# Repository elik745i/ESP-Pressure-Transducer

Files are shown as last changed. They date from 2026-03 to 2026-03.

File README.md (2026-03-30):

# ESP Pressure Transducer

PlatformIO project for a Wemos D1 mini (ESP8266) pressure monitor with:

- 0.96 inch I2C OLED status display
- TTP223 touch sensor support for quick OLED unit switching
- web configuration page with in-firmware fallback if LittleFS content is missing
- Wi-Fi station mode plus fallback configuration access point
- captive portal behavior for easier AP setup on phones and laptops
- MQTT publishing for Home Assistant
- buzzer alarm window with configurable Min and Max limits
- buzzer volume control in the web UI and over MQTT
- touch sensor enable / disable control in the web UI and over MQTT
- Home Assistant MQTT discovery controls for Min / Max alarm settings in bar
- Home Assistant device metadata with a direct LAN configuration page link

## Hardware

Board and connections used by this project:

- Wemos D1 mini / ESP8266
- OLED SCL -> D1 / GPIO5
- OLED SDA -> D2 / GPIO4
- Buzzer -> D5 / GPIO14
- TTP223 touch output -> D6 / GPIO12
- Pressure sensor output -> 10K series resistor -> A0
- A0 -> 33K resistor -> GND

Configured sensor default:

- Full scale pressure: `1200 kPa` (`1.2 MPa`, `12 bar`)
- Default analog interpretation: `0.5 V` to `4.5 V` sensor output maps to `0` to `1200 kPa`

## Circuit Diagram

The wiring used for this project is shown below:

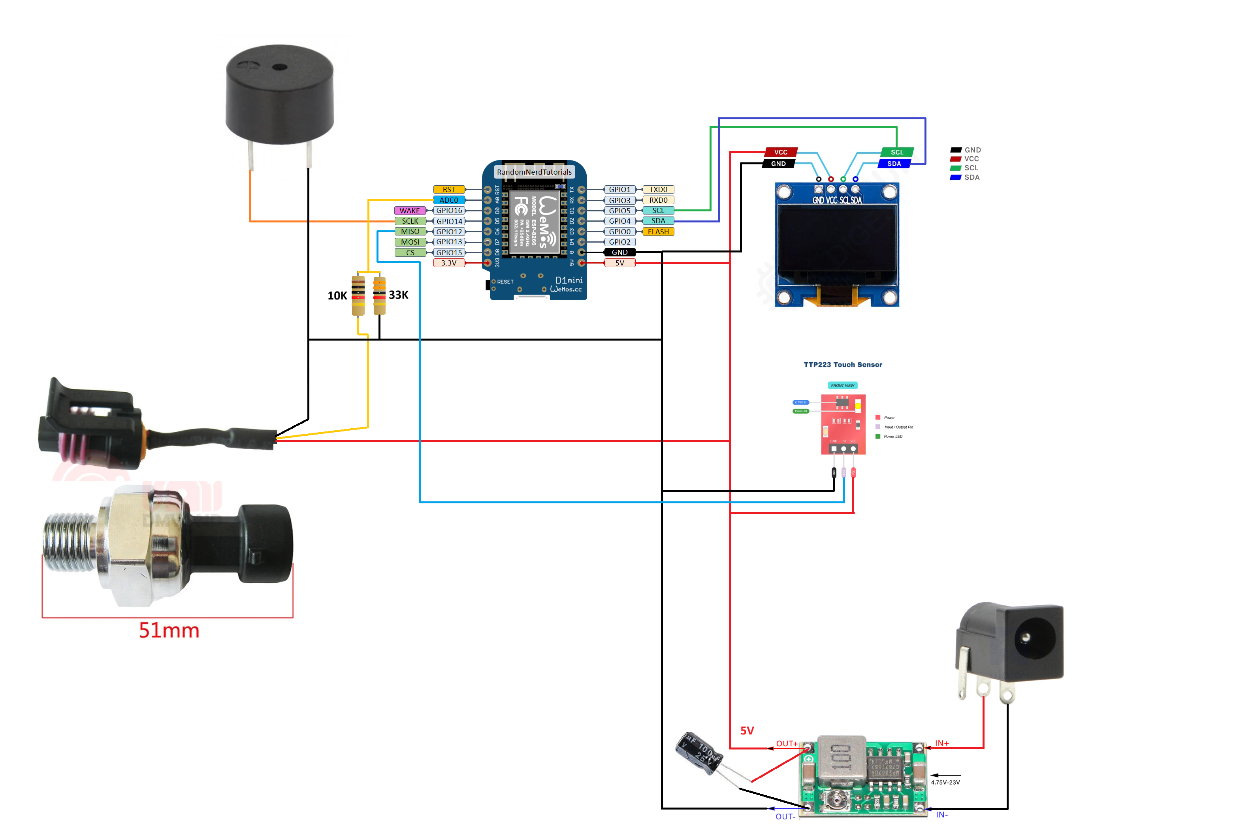
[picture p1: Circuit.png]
Circuit diagram


## Important Analog Note

This firmware assumes the **Wemos D1 mini A0 pin range is 0 to 3.2 V**, then reconstructs the original sensor voltage from your external `10K / 33K` divider.

That divider ratio is:

$$
V_{A0} = V_{sensor} \times \frac{33}{10 + 33} \approx 0.767 \times V_{sensor}
$$

If your sensor is powered at `5 V` and outputs up to `4.5 V`, the divided voltage is about:

$$
4.5 \times 0.767 \approx 3.45 V
$$

That is slightly above the usual safe `3.2 V` limit of a D1 mini A0 pin. If your real hardware reaches that level, reduce the divider ratio before long-term use.

## Project Layout

- [platformio.ini](platformio.ini)
- [src/main.cpp](src/main.cpp)
- [data/index.html](data/index.html)
- [.github/workflows/platformio.yml](.github/workflows/platformio.yml)

## VS Code Setup

1. Open this folder in VS Code.
2. Install the recommended extension: `PlatformIO IDE`.
3. Connect the Wemos D1 mini by USB.
4. In PlatformIO:
   1. Run `Upload` to flash the firmware.
   2. Optionally run `Upload Filesystem Image` to store [data/index.html](data/index.html) in LittleFS too.
   3. Open `Monitor` at `115200` baud if needed.

You can also use the PlatformIO toolbar buttons in the VS Code status bar.

If the PlatformIO status bar buttons are not visible, use VS Code task buttons instead:

1. Open `Terminal -> Run Task`.
2. Use one of these project tasks:
   1. `PlatformIO: Build`
   2. `PlatformIO: Upload`
   3. `PlatformIO: Upload Filesystem`
   4. `PlatformIO: Monitor`
   5. `PlatformIO: Clean`

These tasks are defined in [.vscode/tasks.json](.vscode/tasks.json) so the project remains easy to build and upload from the VS Code interface.

## Flashing Troubleshooting

If flashing fails or the CH340/CH341 serial adapter is not detected correctly on Windows, try installing the older CH341 driver included in this repository:

- [CH341SER/CH341SER.EXE](CH341SER/CH341SER.EXE)

The driver files are stored in the [CH341SER](CH341SER) folder in this git repository.

## First Boot

On first boot the device creates an access point:

- SSID: `PressureConfig-<chipid>`
- Password: `12345678`

Open:

- `http://192.168.4.1`

Many phones and laptops should also open the configuration page automatically through captive portal detection while connected to the device AP.

Set:

- Wi-Fi SSID and password
- MQTT broker host, port, username, password
- MQTT base topic
- Home Assistant discovery prefix
- sensor voltage calibration, full-scale pressure, and buzzer alarm min/max window

After saving, the device restarts automatically.

## OLED Touch Control

If a TTP223 touch sensor is connected to `D6 / GPIO12`, a short touch will:

- play a short confirmation beep on the buzzer
- switch the OLED pressure unit between `bar` and `psi`

This gives a quick way to change units directly on the device without opening the web UI.

The touch sensor can also be disabled entirely from the web UI or over MQTT.

## Firmware Updates

The Firmware tab supports two update methods:

- GitHub release discovery for available versions
- local `firmware.bin` upload through the web page

For ESP8266 reliability, the recommended OTA setup is:

- use GitHub for version discovery and release history
- host the actual `firmware.bin` on a simple direct static URL
- set `OTA Base URL` in the Firmware tab to:
  `https://your-host/esp-pressure-transducer`

Then the device downloads firmware from:

- `https://your-host/esp-pressure-transducer/<version>/firmware.bin`

If `OTA Base URL` is left empty, the firmware falls back to the GitHub release asset URL.

The local upload button is for:

- `firmware.bin`

Do not use `littlefs.bin` with the local upload button. `littlefs.bin` is only for manual flash-tool installs when you intentionally want to refresh the filesystem image.

## MQTT Topics

Default base topic:

- `home/pressure-<chipid>`

Published topics:

- `<baseTopic>/state`
- `<baseTopic>/availability`

The state payload includes:

- `pressure_kpa`
- `pressure_bar`
- `sensor_voltage`
- `a0_voltage`
- `raw_adc`
- `wifi_rssi`
- `ip`
- `alarm`
- `uptime_seconds`

If Home Assistant discovery is enabled, the firmware also publishes discovery topics under:

- `homeassistant/sensor/.../config`
- `homeassistant/number/.../config`

Home Assistant discovery includes:

- pressure sensor exposed in `bar`
- `Min` and `Max` number controls for the buzzer alarm window
- `Buzzer Volume` number control in percent
- `Touch Sensor` switch to enable or disable touch input
- a device `configuration_url` that points to the device's LAN page when Wi-Fi is connected

## GitHub Setup

This project is prepared for git and GitHub upload.

Suggested commands:

```powershell
git init
git checkout -b main
git add .
git commit -m "Initial ESP pressure transducer project"
git remote add origin https://github.com/elik745i/ESP-Pressure-Transducer.git
git push -u origin main
```

The repository already includes a GitHub Actions workflow that builds the PlatformIO project on pushes and pull requests.

## Notes

- Wi-Fi, MQTT, and device identity settings are stored in persistent EEPROM-backed storage so they survive filesystem refreshes.
- AP, calibration, OLED, and other non-critical settings are stored in LittleFS at `/config.json`.
- The web UI is compiled into firmware and can also be stored separately in LittleFS as [data/index.html](data/index.html).
- The Firmware tab can remember the last open tab in the browser and reopen it after refresh.
- The OLED shows live pressure, Wi-Fi state, and MQTT state.
- A TTP223 touch sensor on `D6 / GPIO12` can toggle the OLED between `bar` and `psi` with a short beep.
- Buzzer volume is adjustable from `0` to `100%` and is retained in device configuration.
- Touch sensor enable / disable is retained in device configuration and available over MQTT.
- The alarm logic now uses hysteresis and reports low-side and high-side alarm activity separately in the status payload.
- The built-in LED uses different blink patterns for boot, AP-only mode, Wi-Fi connection attempts, Wi-Fi connected, MQTT connected, and restart pending.

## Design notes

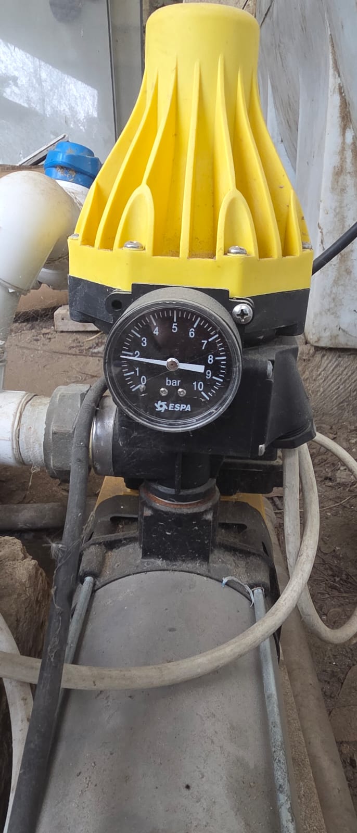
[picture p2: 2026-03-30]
Docs/espa1.jpeg

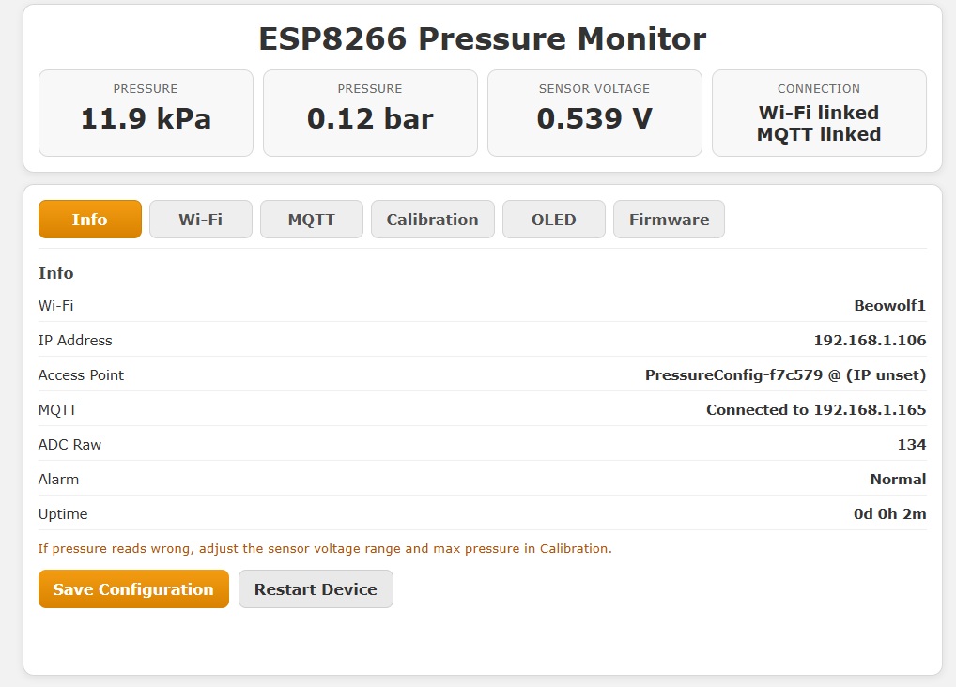
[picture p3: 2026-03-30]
Docs/web.jpg

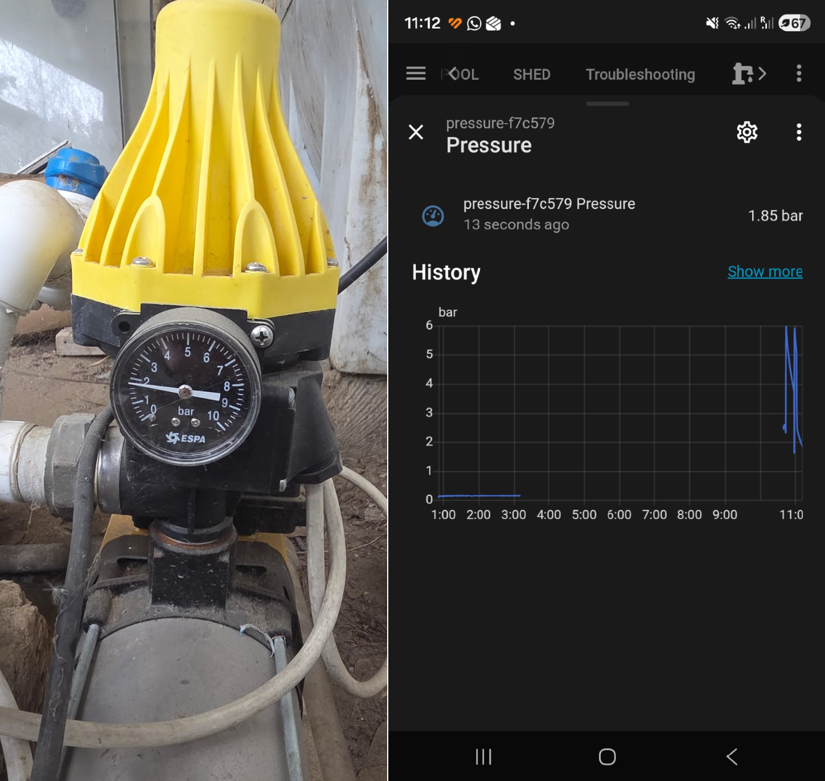
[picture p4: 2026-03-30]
Docs/correction.png

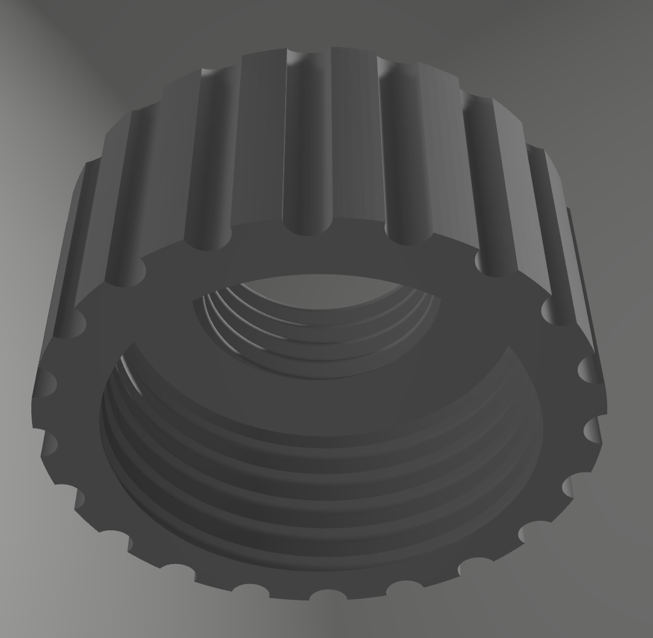
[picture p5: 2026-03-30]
Docs/xover.png

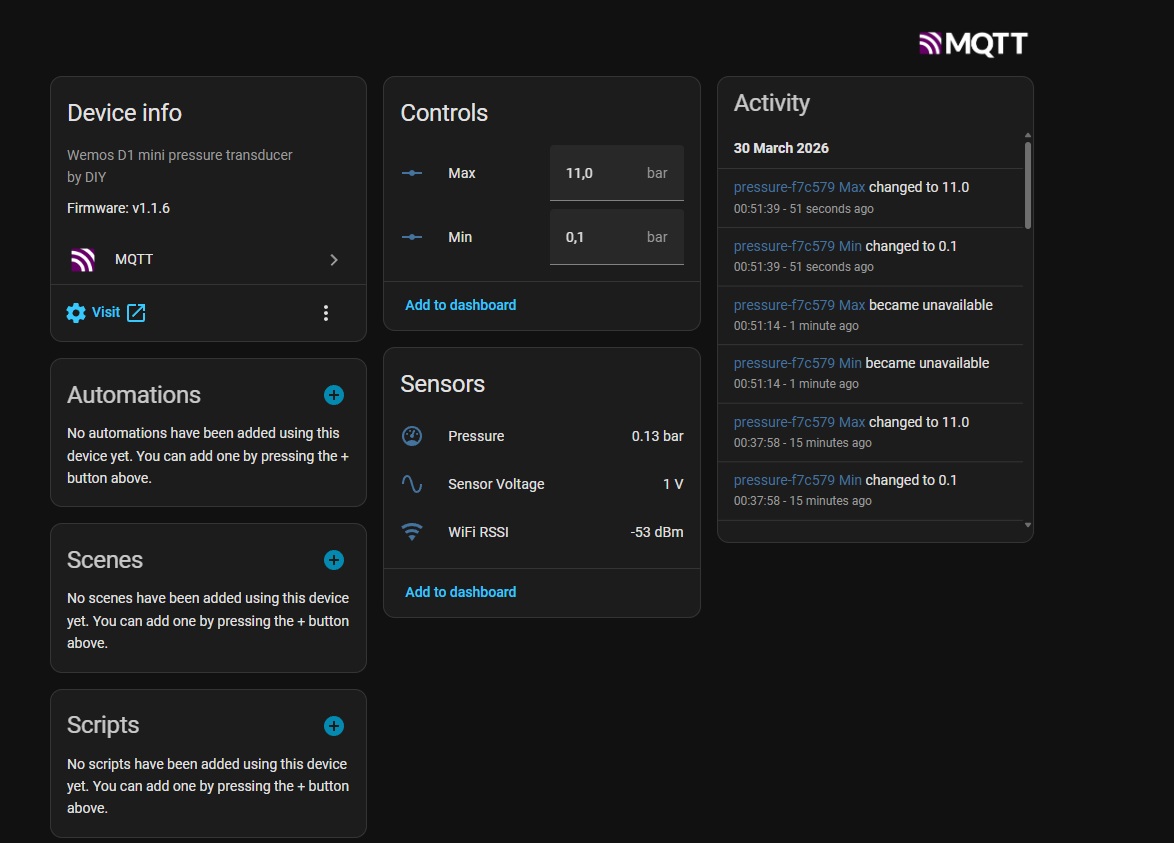
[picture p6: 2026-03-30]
Docs/HA.jpg

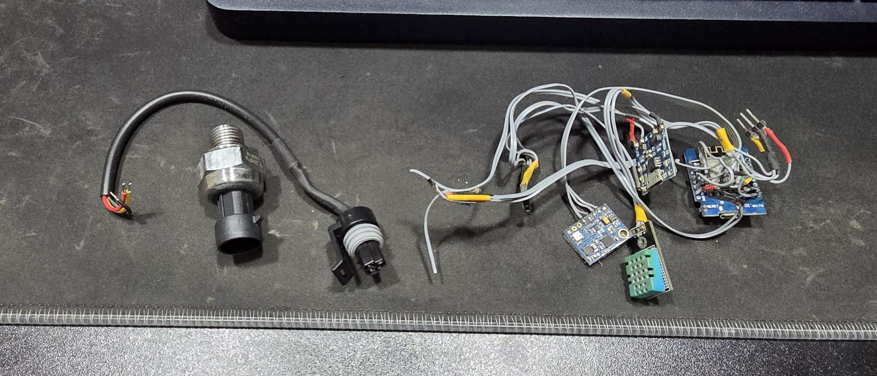
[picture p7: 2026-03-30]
Docs/next_one.jpeg

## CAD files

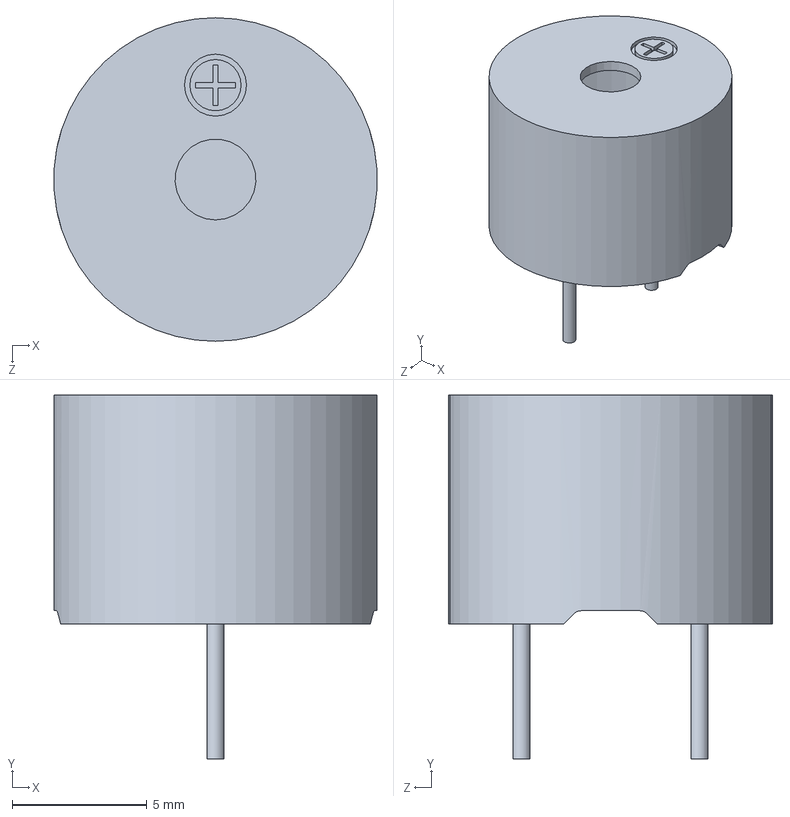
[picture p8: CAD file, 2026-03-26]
3D/3d_Models/buzzer-hc-12085-1.snapshot.1/Buzzer.SLDPRT
12.0 x 13.5 x 12.0 mm

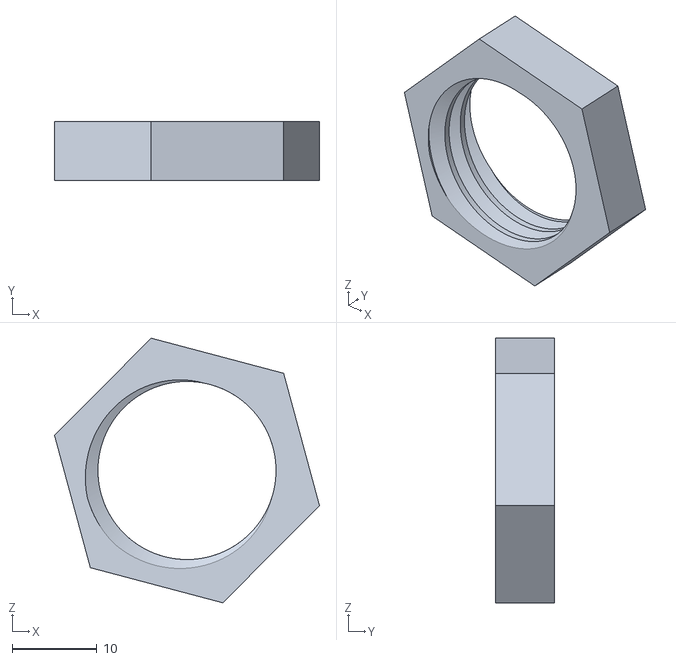
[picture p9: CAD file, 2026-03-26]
3D/3d_Models/cable-gland-18.snapshot.6/sph17mmB.stl
31.3 x 7.00 x 31.2

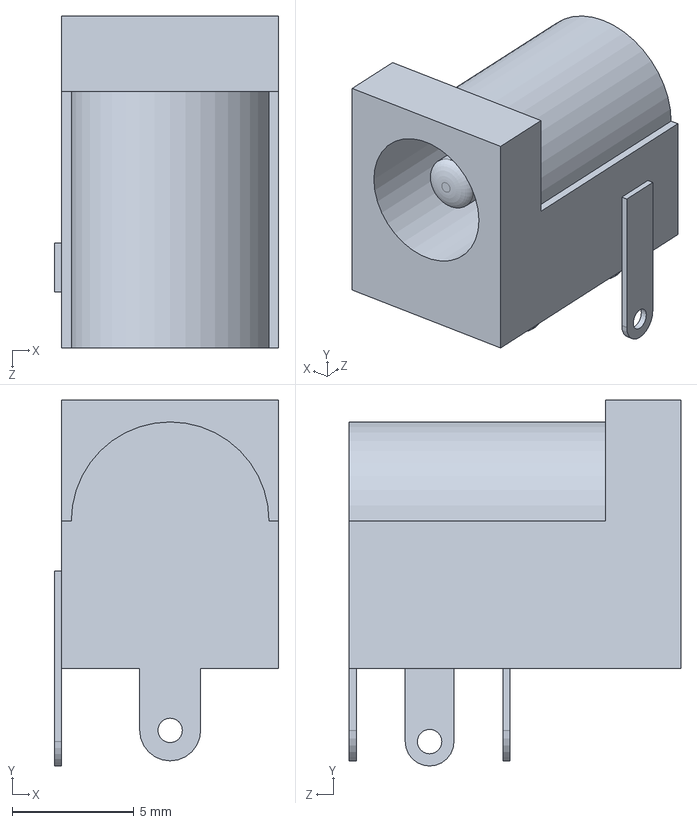
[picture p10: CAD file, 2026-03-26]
3D/3d_Models/jack_dc_2-5-1.snapshot.1/Conector_jack_2.5.SLDPRT
9.20 x 15.0 x 13.6 mm

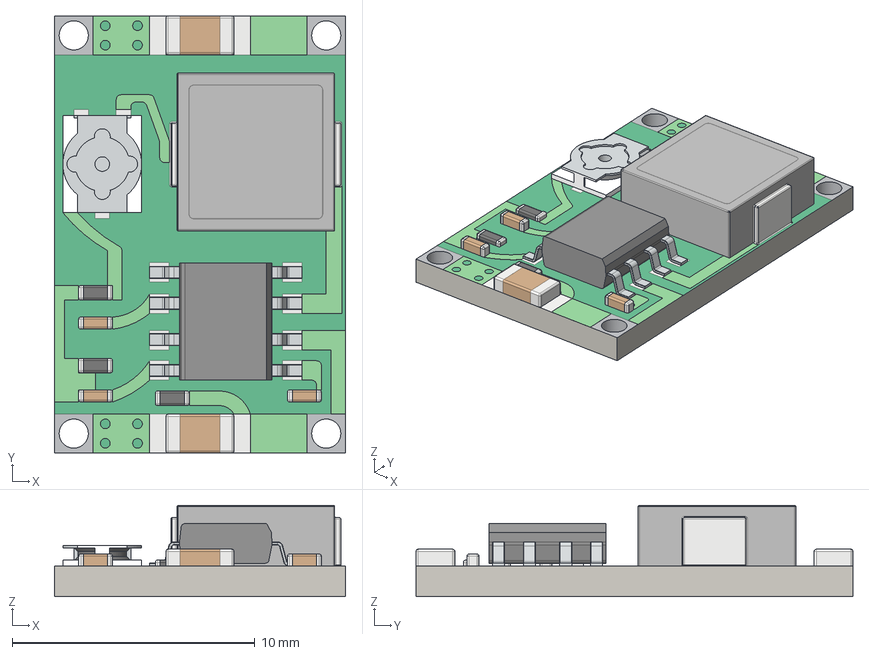
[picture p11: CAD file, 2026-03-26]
3D/3d_Models/mini-360-mp2307-1.snapshot.5/MIni - 360.step
12.0 x 18.0 x 3.75 mm

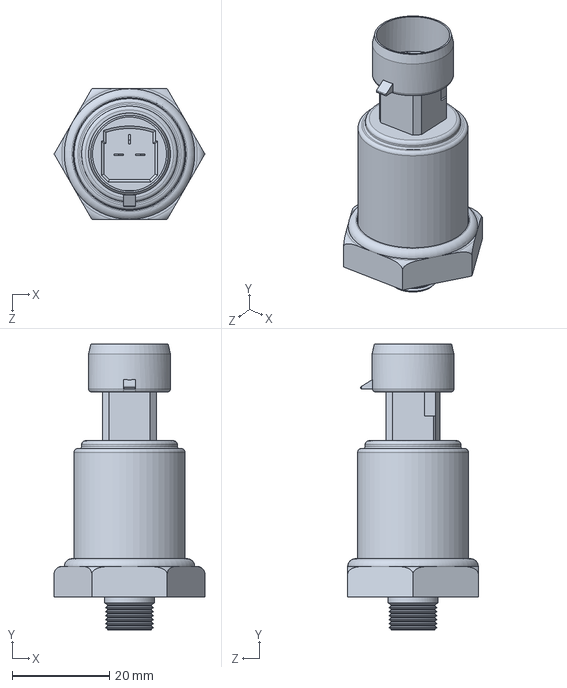
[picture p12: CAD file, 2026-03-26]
3D/3d_Models/mlh100pgb01a-transducer-1.snapshot.11/MLH100PGB01A .STEP
31.1 x 59.0 x 26.9 mm

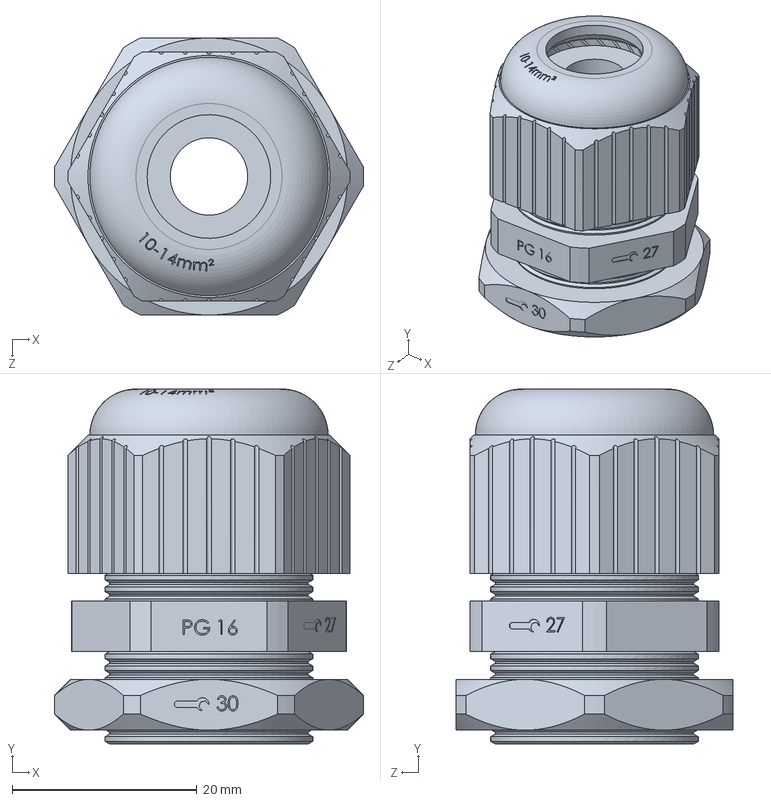
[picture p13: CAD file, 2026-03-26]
3D/3d_Models/polyamid-kablo-rakoru-polyamide-cable-gland-1.snapshot.6/Plastik Kablo Rakoru(PG).SLDPRT
33.5 x 38.4 x 30.0 mm

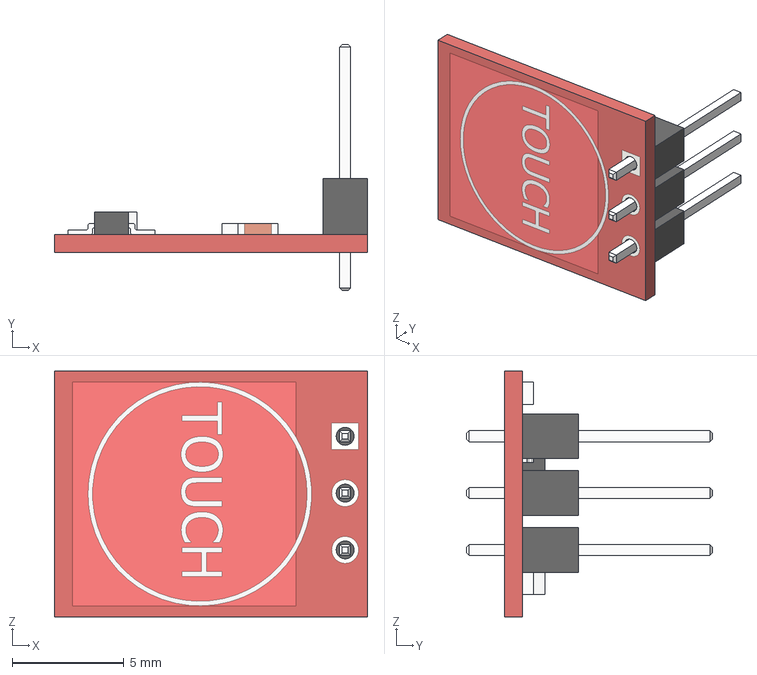
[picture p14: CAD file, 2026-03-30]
3D/3d_Models/touch-sensor-ttp223-1.snapshot.2/TTP223_pin2.stp
14.0 x 11.0 x 11.0 mm

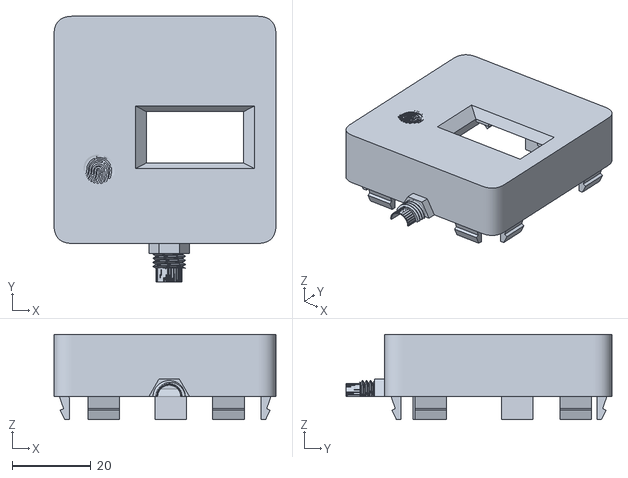
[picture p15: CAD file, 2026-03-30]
3D/STL/ESP_Pressure_Transsducer_top.stl
56.3 x 67.4 x 21.6

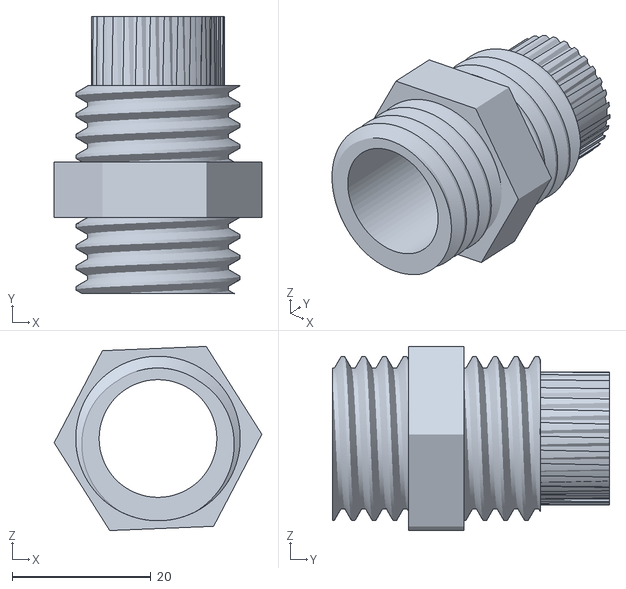
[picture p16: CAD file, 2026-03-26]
3D/3d_Models/cable-gland-18.snapshot.6/sph17mmAv2.stl
30.0 x 40.0 x 26.6

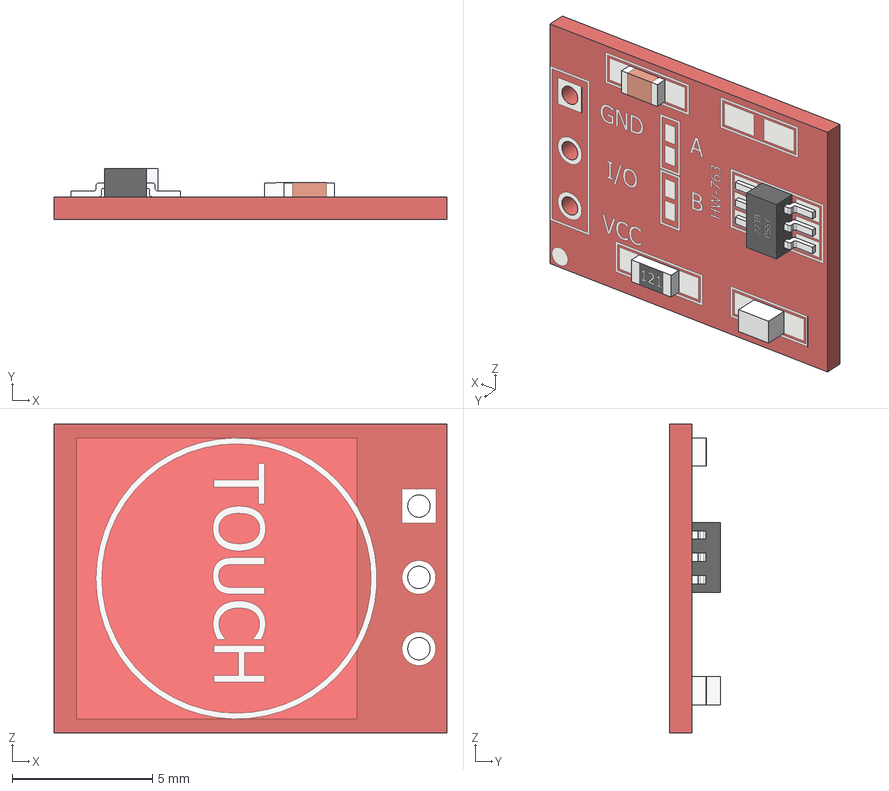
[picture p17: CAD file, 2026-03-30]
3D/3d_Models/touch-sensor-ttp223-1.snapshot.2/TTP223.stp
14.0 x 1.80 x 11.0 mm

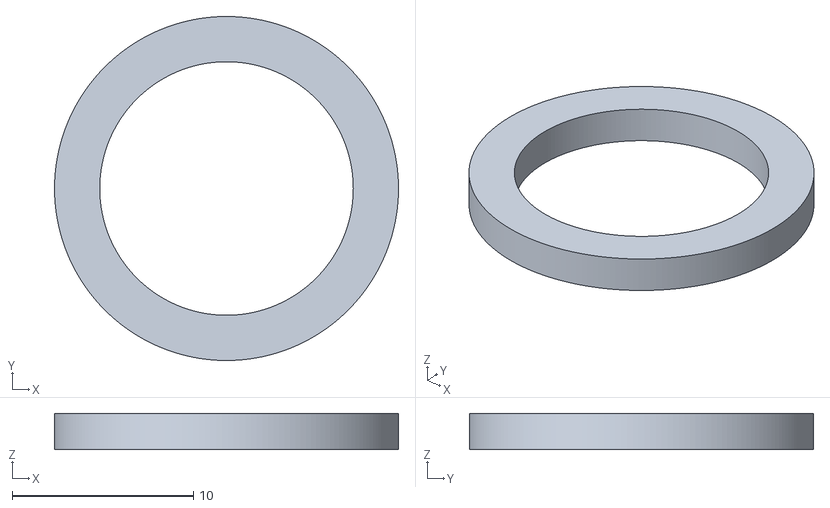
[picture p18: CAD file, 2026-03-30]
3D/STL/Tiiviste.stl
19.0 x 19.0 x 2.00

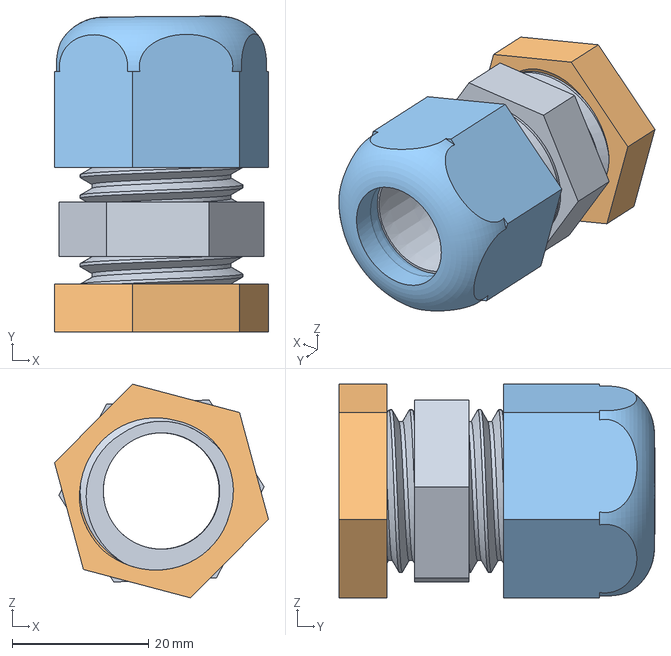
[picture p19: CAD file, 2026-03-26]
3D/3d_Models/cable-gland-18.snapshot.6/sph Cable Glands.step
31.3 x 46.1 x 31.2 mm

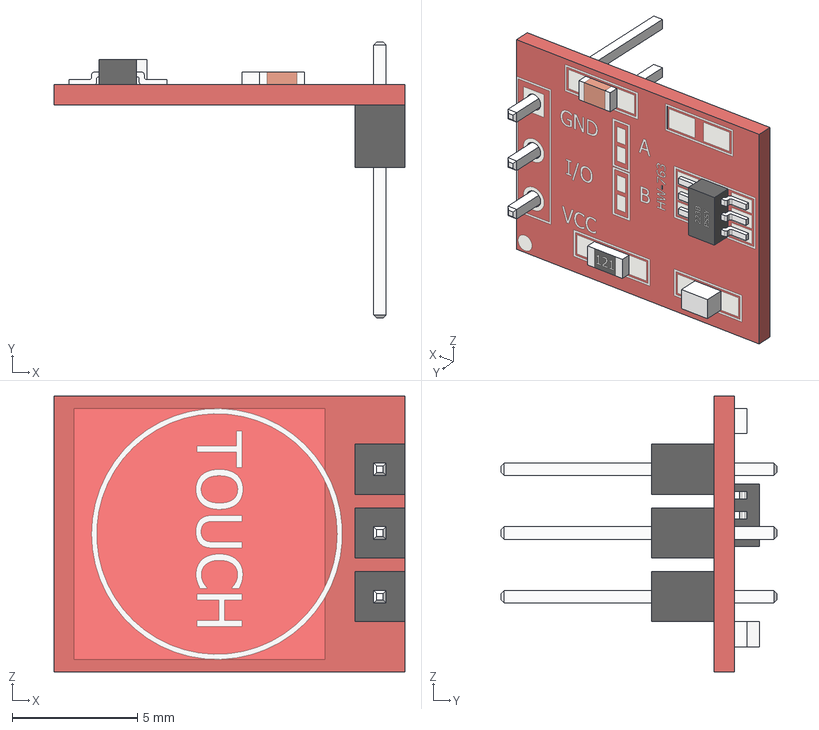
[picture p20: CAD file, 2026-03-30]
3D/3d_Models/touch-sensor-ttp223-1.snapshot.2/TTP223_pin.stp
14.0 x 11.0 x 11.0 mm

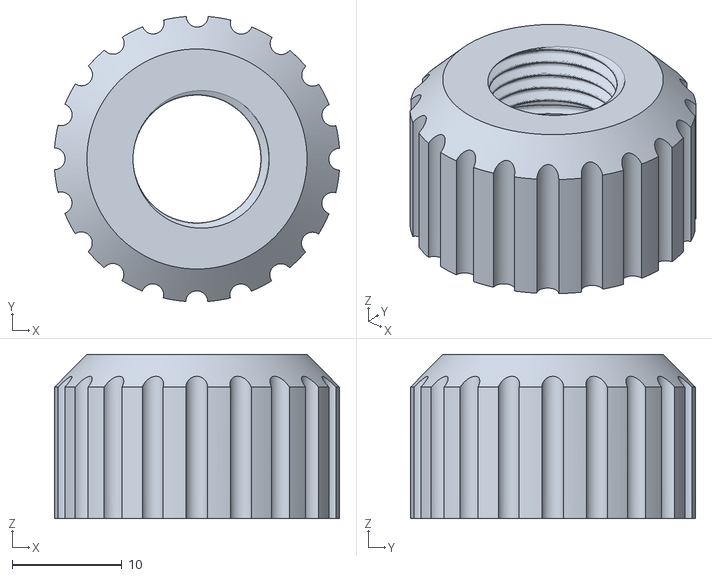
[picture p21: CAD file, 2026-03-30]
3D/STL/Kierre.stl
26.0 x 26.0 x 15.0

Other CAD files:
3D/3d_Models/buzzer-hc-12085-1.snapshot.1/Buzzer_HC-12085.STEP
3D/3d_Models/cable-gland-18.snapshot.6/sph17mmC.stl
3D/STL/ESP_Pressure_Transsducer_bot.3mf
3D/STL/nut.stl
3D/3d_Models/mlh100pgb01a-transducer-1.snapshot.11/MLH100PGB01A .SLDPRT
3D/STL/ESP_Pressure_Transsducer_bot.stl

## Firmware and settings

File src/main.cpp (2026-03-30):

#include <Arduino.h>
#include <EEPROM.h>
#include <LittleFS.h>
#include <ArduinoJson.h>
#include <DNSServer.h>
#include <ESP8266HTTPClient.h>
#include <ESP8266WebServer.h>
#include <ESP8266WiFi.h>
#include <PubSubClient.h>
#include <U8g2lib.h>
#include <Updater.h>
#include <WiFiClientSecureBearSSL.h>
#include "web_ui.h"

namespace {

constexpr char CONFIG_PATH[] = "/config.json";
constexpr char FIRMWARE_VERSION[] = "v1.1.9";
constexpr char GITHUB_OWNER[] = "elik745i";
constexpr char GITHUB_REPO[] = "ESP-Pressure-Transducer";
constexpr char GITHUB_RELEASES_API_URL[] = "https://api.github.com/repos/elik745i/ESP-Pressure-Transducer/releases?per_page=10";
constexpr char GITHUB_TAGS_API_URL[] = "https://api.github.com/repos/elik745i/ESP-Pressure-Transducer/tags?per_page=10";
constexpr char GITHUB_FIRMWARE_ASSET_NAME[] = "firmware.bin";
constexpr char GITHUB_FILESYSTEM_ASSET_NAME[] = "littlefs.bin";
constexpr char OTA_DIRECT_FIRMWARE_PATH[] = "firmware.bin";
constexpr uint8_t BUZZER_PIN = D5;
constexpr uint8_t TOUCH_SENSOR_PIN = D6;
constexpr uint8_t STATUS_LED_PIN = LED_BUILTIN;
constexpr uint16_t DNS_PORT = 53;
constexpr float ADC_PIN_MAX_VOLTAGE = 3.2f;
constexpr float DIVIDER_R1_KOHM = 10.0f;
constexpr float DIVIDER_R2_KOHM = 33.0f;
constexpr float ALARM_HYSTERESIS_KPA = 2.0f;
constexpr unsigned long SENSOR_SAMPLE_INTERVAL_MS = 250;
constexpr unsigned long DISPLAY_INTERVAL_MS = 500;
constexpr unsigned long WIFI_RECONNECT_INTERVAL_MS = 15000;
constexpr unsigned long MQTT_RECONNECT_INTERVAL_MS = 10000;
constexpr unsigned long BOOT_INDICATION_MS = 4000;
constexpr unsigned long TOUCH_SENSOR_DEBOUNCE_MS = 50;
constexpr unsigned long TOUCH_SENSOR_STARTUP_IGNORE_MS = 1500;
constexpr unsigned long TOUCH_SENSOR_RETRIGGER_MS = 700;
constexpr size_t EEPROM_SIZE_BYTES = 1024;
constexpr uint32_t PERSISTENT_CONFIG_MAGIC = 0x50545231UL;
constexpr uint16_t PERSISTENT_CONFIG_VERSION = 1;

struct PersistentConfigData {
  uint32_t magic;
  uint16_t version;
  char deviceName[64];
  char wifiSsid[33];
  char wifiPassword[65];
  char mqttHost[64];
  uint16_t mqttPort;
  char mqttUser[65];
  char mqttPassword[65];
  char mqttBaseTopic[96];
  char mqttDiscoveryPrefix[32];
  uint8_t mqttEnabled;
  uint8_t mqttDiscoveryEnabled;
  uint32_t checksum;
};

struct AppConfig {
  String deviceName;
  String apSsid;
  String apPassword;
  String otaBaseUrl;
  String wifiSsid;
  String wifiPassword;
  String mqttHost;
  uint16_t mqttPort;
  String mqttUser;
  String mqttPassword;
  String mqttBaseTopic;
  String mqttDiscoveryPrefix;
  bool mqttEnabled;
  bool mqttDiscoveryEnabled;
  float sensorMinVoltage;
  float sensorMaxVoltage;
  float sensorMaxPressureKPa;
  String sensorFilterPreset;
  float buzzerAlarmMinPressureKPa;
  float buzzerAlarmMaxPressureKPa;
  float buzzerAlarmThresholdKPa;
  bool buzzerEnabled;
  uint8_t buzzerVolumePercent;
  uint32_t publishIntervalSeconds;
  uint8_t oledContrast;
  bool oledFlip;
  bool touchEnabled;
  String oledPressureUnit;
  String oledTopRowMode;
  String oledBottomRowMode;
  int8_t oledValueYOffset;
};

struct SensorState {
  uint16_t rawAdc = 0;
  float a0Voltage = 0.0f;
  float sensorVoltage = 0.0f;
  float pressureKPa = 0.0f;
  float pressureBar = 0.0f;
  bool alarmActive = false;
};

AppConfig config;
SensorState sensorState;
ESP8266WebServer server(80);
DNSServer dnsServer;
WiFiClient wifiClient;
PubSubClient mqttClient(wifiClient);
U8G2_SSD1306_128X64_NONAME_F_HW_I2C display(U8G2_R0, U8X8_PIN_NONE);

unsigned long lastSensorSampleMs = 0;
unsigned long lastDisplayMs = 0;
unsigned long lastWifiReconnectAttemptMs = 0;
unsigned long lastMqttReconnectAttemptMs = 0;
unsigned long lastPublishMs = 0;
unsigned long lastAlarmToneMs = 0;
bool restartRequested = false;
unsigned long restartAtMs = 0;
bool mqttDiscoveryPublished = false;
bool wasWifiConnected = false;
bool wasMqttConnected = false;
bool accessPointEnabled = false;
bool otaUpdateRequested = false;
bool otaUpdateRunning = false;
uint8_t otaProgressPercent = 0;
String otaStatusMessage = "Idle";
String otaUpdateVersion = "";
String otaFirmwareUrl = "";
String otaCurrentPhase = "";
size_t otaProgressCurrentBytes = 0;
size_t otaProgressTotalBytes = 0;
bool localFirmwareUploadOk = false;
bool localFirmwareUploadStarted = false;
bool localFirmwareUploadHadData = false;
String localFirmwareUploadError = "";
String localFirmwareUploadFilename = "";
bool touchSensorPressed = false;
bool touchSensorRawPressed = false;
unsigned long touchSensorStateChangedAtMs = 0;
unsigned long touchSensorIgnoreUntilMs = 0;
unsigned long lastTouchTriggerMs = 0;
bool lowPressureAlarmActive = false;
bool highPressureAlarmActive = false;
const uint16_t *buzzerMelodyFrequencies = nullptr;
const uint16_t *buzzerMelodyDurations = nullptr;
size_t buzzerMelodyCount = 0;
size_t buzzerMelodyIndex = 0;
bool buzzerMelodyActive = false;
bool buzzerTonePhase = false;
unsigned long buzzerPhaseEndsAtMs = 0;
constexpr uint16_t BOOT_MELODY_FREQUENCIES[] = {1960, 2470, 2940};
constexpr uint16_t BOOT_MELODY_DURATIONS[] = {90, 90, 140};
constexpr uint16_t WIFI_CONNECTED_MELODY_FREQUENCIES[] = {1760, 2200, 2620};
constexpr uint16_t WIFI_CONNECTED_MELODY_DURATIONS[] = {90, 90, 130};
constexpr uint16_t WIFI_DISCONNECTED_MELODY_FREQUENCIES[] = {2620, 1960, 1470};
constexpr uint16_t WIFI_DISCONNECTED_MELODY_DURATIONS[] = {100, 100, 140};
constexpr uint16_t MQTT_CONNECTED_MELODY_FREQUENCIES[] = {1560, 2080, 1560, 3120};
constexpr uint16_t MQTT_CONNECTED_MELODY_DURATIONS[] = {70, 70, 70, 150};

enum class LedPattern {
  Booting,
  ApOnly,
  WifiConnecting,
  WifiConnected,
  WifiAndMqttConnected,
  RestartPending,
};

void scheduleRestart(unsigned long delayMs);
float clampFloat(float value, float low, float high);
void publishState();
void drawDisplay();

String defaultDeviceName() {
  return String("pressure-") + String(ESP.getChipId(), HEX);
}

String defaultApSsid() {
  return String("PressureConfig-") + String(ESP.getChipId(), HEX);
}

uint32_t persistentConfigChecksum(const PersistentConfigData &data) {
  const uint8_t *bytes = reinterpret_cast<const uint8_t *>(&data);
  const size_t checksumOffset = offsetof(PersistentConfigData, checksum);
  uint32_t hash = 2166136261UL;
  for (size_t index = 0; index < checksumOffset; ++index) {
    hash ^= bytes[index];
    hash *= 16777619UL;
  }
  return hash;
}

void writeFixedString(char *target, size_t size, const String &value) {
  if (size == 0) {
    return;
  }
  memset(target, 0, size);
  value.substring(0, size - 1).toCharArray(target, size);
}

String readFixedString(const char *value, size_t size) {
  size_t length = 0;
  while (length < size && value[length] != '\0') {
    ++length;
  }
  return String(value).substring(0, length);
}

bool loadPersistentConfig() {
  PersistentConfigData stored{};
  EEPROM.get(0, stored);

  if (stored.magic != PERSISTENT_CONFIG_MAGIC ||
      stored.version != PERSISTENT_CONFIG_VERSION ||
      stored.checksum != persistentConfigChecksum(stored)) {
    return false;
  }

  config.deviceName = readFixedString(stored.deviceName, sizeof(stored.deviceName));
  config.wifiSsid = readFixedString(stored.wifiSsid, sizeof(stored.wifiSsid));
  config.wifiPassword = readFixedString(stored.wifiPassword, sizeof(stored.wifiPassword));
  config.mqttHost = readFixedString(stored.mqttHost, sizeof(stored.mqttHost));
  config.mqttPort = stored.mqttPort;
  config.mqttUser = readFixedString(stored.mqttUser, sizeof(stored.mqttUser));
  config.mqttPassword = readFixedString(stored.mqttPassword, sizeof(stored.mqttPassword));
  config.mqttBaseTopic = readFixedString(stored.mqttBaseTopic, sizeof(stored.mqttBaseTopic));
  config.mqttDiscoveryPrefix = readFixedString(stored.mqttDiscoveryPrefix, sizeof(stored.mqttDiscoveryPrefix));
  config.mqttEnabled = stored.mqttEnabled != 0;
  config.mqttDiscoveryEnabled = stored.mqttDiscoveryEnabled != 0;

  if (config.deviceName.isEmpty()) {
    config.deviceName = defaultDeviceName();
  }
  if (config.mqttPort == 0) {
    config.mqttPort = 1883;
  }
  if (config.mqttBaseTopic.isEmpty()) {
    config.mqttBaseTopic = String("home/") + config.deviceName;
  }
  if (config.mqttDiscoveryPrefix.isEmpty()) {
    config.mqttDiscoveryPrefix = "homeassistant";
  }
  return true;
}

bool savePersistentConfig() {
  PersistentConfigData stored{};
  stored.magic = PERSISTENT_CONFIG_MAGIC;
  stored.version = PERSISTENT_CONFIG_VERSION;
  writeFixedString(stored.deviceName, sizeof(stored.deviceName), config.deviceName);
  writeFixedString(stored.wifiSsid, sizeof(stored.wifiSsid), config.wifiSsid);
  writeFixedString(stored.wifiPassword, sizeof(stored.wifiPassword), config.wifiPassword);
  writeFixedString(stored.mqttHost, sizeof(stored.mqttHost), config.mqttHost);
  stored.mqttPort = config.mqttPort;
  writeFixedString(stored.mqttUser, sizeof(stored.mqttUser), config.mqttUser);
  writeFixedString(stored.mqttPassword, sizeof(stored.mqttPassword), config.mqttPassword);
  writeFixedString(stored.mqttBaseTopic, sizeof(stored.mqttBaseTopic), config.mqttBaseTopic);
  writeFixedString(stored.mqttDiscoveryPrefix, sizeof(stored.mqttDiscoveryPrefix), config.mqttDiscoveryPrefix);
  stored.mqttEnabled = config.mqttEnabled ? 1 : 0;
  stored.mqttDiscoveryEnabled = config.mqttDiscoveryEnabled ? 1 : 0;
  stored.checksum = persistentConfigChecksum(stored);

  EEPROM.put(0, stored);
  return EEPROM.commit();
}

void setDefaults() {
  config.deviceName = defaultDeviceName();
  config.apSsid = defaultApSsid();
  config.apPassword = "12345678";
  config.otaBaseUrl = "";
  config.wifiSsid = "";
  config.wifiPassword = "";
  config.mqttHost = "";
  config.mqttPort = 1883;
  config.mqttUser = "";
  config.mqttPassword = "";
  config.mqttBaseTopic = String("home/") + config.deviceName;
  config.mqttDiscoveryPrefix = "homeassistant";
  config.mqttEnabled = false;
  config.mqttDiscoveryEnabled = true;
  config.sensorMinVoltage = 0.5f;
  config.sensorMaxVoltage = 4.5f;
  config.sensorMaxPressureKPa = 1200.0f;
  config.sensorFilterPreset = "none";
  config.buzzerAlarmMinPressureKPa = 0.0f;
  config.buzzerAlarmMaxPressureKPa = 1100.0f;
  config.buzzerAlarmThresholdKPa = 1100.0f;
  config.buzzerEnabled = true;
  config.buzzerVolumePercent = 50;
  config.publishIntervalSeconds = 15;
  config.oledContrast = 200;
  config.oledFlip = false;
  config.touchEnabled = true;
  config.oledPressureUnit = "bar";
  config.oledTopRowMode = "ip";
  config.oledBottomRowMode = "mqtt";
  config.oledValueYOffset = 3;
}

bool saveConfig() {
  JsonDocument doc;
  doc["apSsid"] = config.apSsid;
  doc["apPassword"] = config.apPassword;
  doc["otaBaseUrl"] = config.otaBaseUrl;
  doc["sensorMinVoltage"] = config.sensorMinVoltage;
  doc["sensorMaxVoltage"] = config.sensorMaxVoltage;
  doc["sensorMaxPressureKPa"] = config.sensorMaxPressureKPa;
  doc["sensorFilterPreset"] = config.sensorFilterPreset;
  doc["buzzerAlarmMinPressureKPa"] = config.buzzerAlarmMinPressureKPa;
  doc["buzzerAlarmMaxPressureKPa"] = config.buzzerAlarmMaxPressureKPa;
  doc["buzzerAlarmThresholdKPa"] = config.buzzerAlarmThresholdKPa;
  doc["buzzerEnabled"] = config.buzzerEnabled;
  doc["buzzerVolumePercent"] = config.buzzerVolumePercent;
  doc["publishIntervalSeconds"] = config.publishIntervalSeconds;
  doc["oledContrast"] = config.oledContrast;
  doc["oledFlip"] = config.oledFlip;
  doc["touchEnabled"] = config.touchEnabled;
  doc["oledPressureUnit"] = config.oledPressureUnit;
  doc["oledTopRowMode"] = config.oledTopRowMode;
  doc["oledBottomRowMode"] = config.oledBottomRowMode;
  doc["oledValueYOffset"] = config.oledValueYOffset;

  File file = LittleFS.open(CONFIG_PATH, "w");
  if (!file) {
    return false;
  }

  const bool ok = serializeJson(doc, file) > 0;
  file.close();
  return ok;
}

bool loadConfig() {
  setDefaults();
  const bool hasPersistentConfig = loadPersistentConfig();

  if (!LittleFS.exists(CONFIG_PATH)) {
    if (!hasPersistentConfig) {
      savePersistentConfig();
    }
    return saveConfig();
  }

  File file = LittleFS.open(CONFIG_PATH, "r");
  if (!file) {
    return hasPersistentConfig ? saveConfig() : false;
  }

  JsonDocument doc;
  DeserializationError error = deserializeJson(doc, file);
  file.close();
  if (error) {
    return hasPersistentConfig ? saveConfig() : false;
  }

  config.apSsid = doc["apSsid"] | config.apSsid;
  config.apPassword = doc["apPassword"] | config.apPassword;
  config.otaBaseUrl = doc["otaBaseUrl"] | config.otaBaseUrl;
  config.sensorMinVoltage = doc["sensorMinVoltage"] | config.sensorMinVoltage;
  config.sensorMaxVoltage = doc["sensorMaxVoltage"] | config.sensorMaxVoltage;
  config.sensorMaxPressureKPa = doc["sensorMaxPressureKPa"] | config.sensorMaxPressureKPa;
  config.sensorFilterPreset = doc["sensorFilterPreset"] | config.sensorFilterPreset;
  config.buzzerAlarmMinPressureKPa = doc["buzzerAlarmMinPressureKPa"] | config.buzzerAlarmMinPressureKPa;
  config.buzzerAlarmMaxPressureKPa = doc["buzzerAlarmMaxPressureKPa"] | config.buzzerAlarmMaxPressureKPa;
  config.buzzerAlarmThresholdKPa = doc["buzzerAlarmThresholdKPa"] | config.buzzerAlarmThresholdKPa;
  config.buzzerEnabled = doc["buzzerEnabled"] | config.buzzerEnabled;
  config.buzzerVolumePercent = doc["buzzerVolumePercent"] | config.buzzerVolumePercent;
  config.publishIntervalSeconds = doc["publishIntervalSeconds"] | config.publishIntervalSeconds;
  config.oledContrast = doc["oledContrast"] | config.oledContrast;
  config.oledFlip = doc["oledFlip"] | config.oledFlip;
  config.touchEnabled = doc["touchEnabled"] | config.touchEnabled;
  config.oledPressureUnit = doc["oledPressureUnit"] | config.oledPressureUnit;
  config.oledTopRowMode = doc["oledTopRowMode"] | config.oledTopRowMode;
  config.oledBottomRowMode = doc["oledBottomRowMode"] | config.oledBottomRowMode;
  config.oledValueYOffset = doc["oledValueYOffset"] | config.oledValueYOffset;

  if (doc["buzzerAlarmMinPressureKPa"].isNull() && doc["buzzerAlarmMaxPressureKPa"].isNull()) {
    config.buzzerAlarmMinPressureKPa = 0.0f;
    config.buzzerAlarmMaxPressureKPa = config.buzzerAlarmThresholdKPa;
  }

  config.buzzerAlarmMinPressureKPa = clampFloat(config.buzzerAlarmMinPressureKPa, 0.0f, config.sensorMaxPressureKPa);
  config.buzzerAlarmMaxPressureKPa = clampFloat(config.buzzerAlarmMaxPressureKPa, config.buzzerAlarmMinPressureKPa, config.sensorMaxPressureKPa);
  config.buzzerVolumePercent = static_cast<uint8_t>(clampFloat(config.buzzerVolumePercent, 0.0f, 100.0f));

  if (!hasPersistentConfig) {
    config.deviceName = doc["deviceName"] | config.deviceName;
    config.wifiSsid = doc["wifiSsid"] | config.wifiSsid;
    config.wifiPassword = doc["wifiPassword"] | config.wifiPassword;
    config.mqttHost = doc["mqttHost"] | config.mqttHost;
    config.mqttPort = doc["mqttPort"] | config.mqttPort;
    config.mqttUser = doc["mqttUser"] | config.mqttUser;
    config.mqttPassword = doc["mqttPassword"] | config.mqttPassword;
    config.mqttBaseTopic = doc["mqttBaseTopic"] | config.mqttBaseTopic;
    config.mqttDiscoveryPrefix = doc["mqttDiscoveryPrefix"] | config.mqttDiscoveryPrefix;
    config.mqttEnabled = doc["mqttEnabled"] | config.mqttEnabled;
    config.mqttDiscoveryEnabled = doc["mqttDiscoveryEnabled"] | config.mqttDiscoveryEnabled;
    savePersistentConfig();
    saveConfig();
  }
  return true;
}

void applyDisplaySettings() {
  display.setContrast(config.oledContrast);
  display.setFlipMode(config.oledFlip ? 1 : 0);
}

String localIpString() {
  return WiFi.isConnected() ? WiFi.localIP().toString() : String("not connected");
}

String devicePageUrl() {
  if (WiFi.isConnected()) {
    return String("http://") + WiFi.localIP().toString();
  }
  if (accessPointEnabled) {
    return String("http://") + WiFi.softAPIP().toString();
  }
  return "";
}

float displayedPressureValue() {
  if (config.oledPressureUnit == "psi") {
    return sensorState.pressureKPa * 0.1450377f;
  }
  if (config.oledPressureUnit == "mpa") {
    return sensorState.pressureKPa / 1000.0f;
  }
  return sensorState.pressureBar;
}

uint8_t displayedPressureDecimals() {
  if (config.oledPressureUnit == "psi") {
    return 1;
  }
  if (config.oledPressureUnit == "mpa") {
    return 3;
  }
  return 2;
}

String displayedPressureLabel() {
  if (config.oledPressureUnit == "psi") {
    return "psi";
  }
  if (config.oledPressureUnit == "mpa") {
    return "MPa";
  }
  return "bar";
}

String oledTopRowText() {
  if (config.oledTopRowMode == "wifi") {
    return WiFi.isConnected() ? String("WiFi ") + WiFi.SSID() : String("AP ") + config.apSsid;
  }
  if (config.oledTopRowMode == "device") {
    return config.deviceName;
  }
  if (config.oledTopRowMode == "topic") {
    return config.mqttBaseTopic;
  }
  return String(WiFi.isConnected() ? "IP " : "AP ") +
         (WiFi.isConnected() ? WiFi.localIP().toString() : WiFi.softAPIP().toString());
}

String oledBottomRowText() {
  if (config.oledBottomRowMode == "blank") {
    return "";
  }
  if (config.oledBottomRowMode == "wifi") {
    return WiFi.isConnected() ? String("WiFi ") + WiFi.SSID() : "WiFi offline";
  }
  if (config.oledBottomRowMode == "kpa") {
    return String(sensorState.pressureKPa, 1) + " kPa";
  }
  if (config.oledBottomRowMode == "raw") {
    return String("ADC ") + sensorState.rawAdc;
  }
  return mqttClient.connected() ? "MQTT online" : "MQTT offline";
}

float sensorFilterAlpha() {
  if (config.sensorFilterPreset == "none") {
    return 1.0f;
  }
  if (config.sensorFilterPreset == "light") {
    return 0.55f;
  }
  if (config.sensorFilterPreset == "hard") {
    return 0.18f;
  }
  if (config.sensorFilterPreset == "strong") {
    return 0.10f;
  }
  return 0.30f;
}

String mqttClientId() {
  String clientId = config.deviceName;
  clientId.replace(" ", "-");
  return clientId;
}

String stateTopic() {
  return config.mqttBaseTopic + "/state";
}

String availabilityTopic() {
  return config.mqttBaseTopic + "/availability";
}

float kPaToBar(float pressureKPa) {
  return pressureKPa / 100.0f;
}

float barToKPa(float pressureBar) {
  return pressureBar * 100.0f;
}

String alarmMinPressureStateTopic() {
  return config.mqttBaseTopic + "/alarm_min_pressure/state";
}

String alarmMinPressureCommandTopic() {
  return config.mqttBaseTopic + "/alarm_min_pressure/set";
}

String alarmMaxPressureStateTopic() {
  return config.mqttBaseTopic + "/alarm_max_pressure/state";
}

String alarmMaxPressureCommandTopic() {
  return config.mqttBaseTopic + "/alarm_max_pressure/set";
}

String buzzerVolumeStateTopic() {
  return config.mqttBaseTopic + "/buzzer_volume/state";
}

String buzzerVolumeCommandTopic() {
  return config.mqttBaseTopic + "/buzzer_volume/set";
}

String touchEnabledStateTopic() {
  return config.mqttBaseTopic + "/touch_enabled/state";
}

String touchEnabledCommandTopic() {
  return config.mqttBaseTopic + "/touch_enabled/set";
}

String uniqueIdBase() {
  String id = config.deviceName;
  id.replace(" ", "_");
  id.toLowerCase();
  return id;
}

String githubUserAgent() {
  return String("ESP-Pressure-Transducer/") + FIRMWARE_VERSION;
}

void otaDebug(const String &message) {
  Serial.print(F("[OTA] "));
  Serial.println(message);
}

uint16_t buzzerDutyCycle() {
  const float normalized = clampFloat(static_cast<float>(config.buzzerVolumePercent), 0.0f, 100.0f) / 100.0f;
  return static_cast<uint16_t>(normalized * 1023.0f);
}

void stopBuzzerOutput() {
  analogWrite(BUZZER_PIN, 0);
  digitalWrite(BUZZER_PIN, LOW);
}

void startBuzzerOutput(uint16_t frequency) {
  const uint16_t dutyCycle = buzzerDutyCycle();
  if (dutyCycle == 0) {
    stopBuzzerOutput();
    return;
  }

  analogWriteFreq(frequency);
  analogWrite(BUZZER_PIN, dutyCycle);
}

String githubReleaseAssetUrl(const String &tagName, const char *assetName) {
  return String("https://github.com/") + GITHUB_OWNER + "/" + GITHUB_REPO +
         "/releases/download/" + tagName + "/" + assetName;
}

String normalizedOtaBaseUrl() {
  String baseUrl = config.otaBaseUrl;
  baseUrl.trim();
  while (baseUrl.endsWith("/")) {
    baseUrl.remove(baseUrl.length() - 1);
  }
  return baseUrl;
}

bool otaBaseUrlConfigured() {
  return !normalizedOtaBaseUrl().isEmpty();
}

String otaDirectDownloadUrl(const String &tagName, const char *assetName) {
  const String baseUrl = normalizedOtaBaseUrl();
  if (baseUrl.isEmpty()) {
    return "";
  }
  return baseUrl + "/" + tagName + "/" + assetName;
}

String chooseReleaseAssetUrl(const JsonVariantConst &assets, const char *assetName) {
  if (!assets.is<JsonArrayConst>()) {
    return "";
  }

  for (JsonObjectConst asset : assets.as<JsonArrayConst>()) {
    const String name = String(static_cast<const char *>(asset["name"] | ""));
    const String url = String(static_cast<const char *>(asset["browser_download_url"] | ""));
    if (name == assetName && !url.isEmpty()) {
      return url;
    }
  }
  return "";
}
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
void loop() {
  loopApp();
}

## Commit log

2026-03-26 Initial ESP pressure transducer project
    [Buzzer.SLDPRT, Buzzer_HC-12085.STEP, Conector_jack_2.5.SLDPRT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]
2026-03-26 Improve setup UI, buzzer cues, and captive portal flow
    [ESP_Pressure_Transsducer_top.stl]
2026-03-30 Add updated circuit diagram, photos, and STL files
    [Kierre.stl, Tiiviste.stl]
2026-03-30 Update 3D assets and reorganize docs
    [ESP_Pressure_Transsducer_top.stl, TTP223.stp, TTP223_pin.stp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]
